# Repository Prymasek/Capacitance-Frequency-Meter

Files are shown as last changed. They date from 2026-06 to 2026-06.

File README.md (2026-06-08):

<div align="center">

# 🔬 ESP32-C3-Zero Capacitance & Frequency Meter

### Compact open-source capacitance and frequency meter

### Kompaktowy miernik pojemności i częstotliwości

<br>

🇵🇱 **Polski** | 🇬🇧 **English**

<br>

</div>

---

# 🇵🇱 Polski

## 📖 Opis projektu

**ESP32-C3-Zero Capacitance & Frequency Meter** to kompaktowy, otwartoźródłowy miernik pojemności oraz częstotliwości oparty na mikrokontrolerze **ESP32-C3-Zero**.

Projekt został stworzony jako niedrogie i praktyczne narzędzie pomiarowe do pracy z elektroniką. Urządzenie pozwala mierzyć pojemność kondensatorów od około **33 pF** oraz częstotliwość sygnałów cyfrowych do **250 kHz**.

Repozytorium zawiera zarówno część programową, jak i sprzętową projektu: firmware, schemat oraz projekt PCB wykonany w **KiCad 9.0**.

---

## 📸 Zdjęcia projektu

<div align="center">

### Gotowe urządzenie

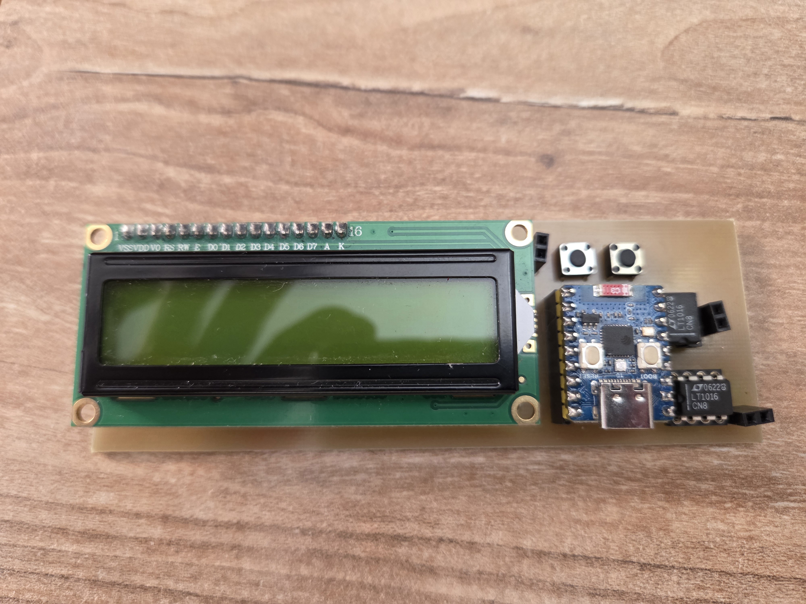
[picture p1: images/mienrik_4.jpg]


<br><br>

### Spód płytki PCB

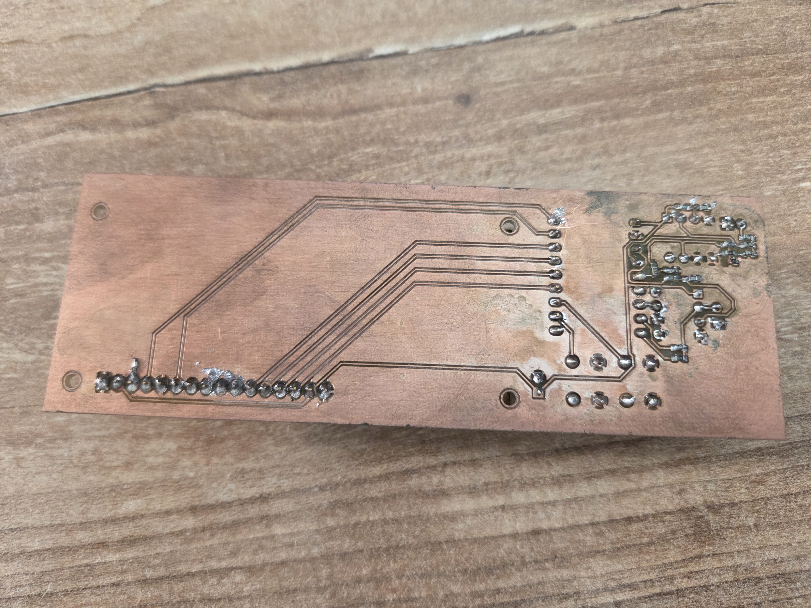
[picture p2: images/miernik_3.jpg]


<br><br>

### Wizualizacja 3D PCB

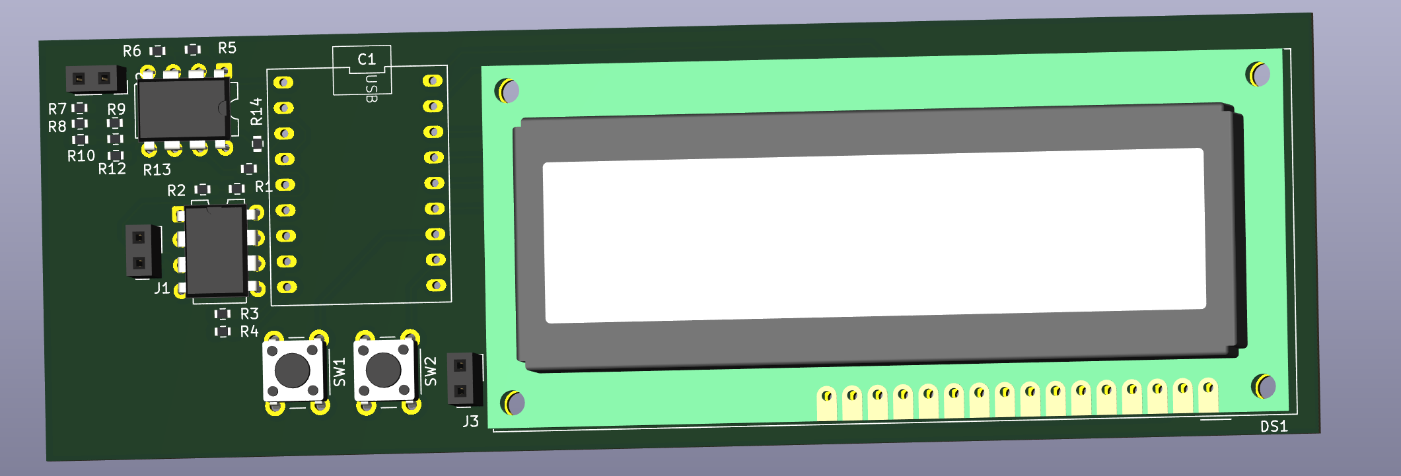
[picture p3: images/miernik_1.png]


</div>

---

## ✨ Najważniejsze funkcje

* ⚡ Pomiar pojemności kondensatorów
* 📡 Pomiar częstotliwości sygnałów
* 🔁 Automatyczny dobór zakresu pomiarowego
* 🎯 Funkcja TARE do kompensacji pojemności pasożytniczej
* ⏸️ Funkcja zatrzymania pomiaru częstotliwości
* 🧩 Projekt PCB wykonany w KiCad 9.0
* 🔓 Otwarty kod źródłowy
* 🛠️ Możliwość dalszej rozbudowy projektu

---

## ⚙️ Zasada działania

### ⚡ Pomiar pojemności

Pomiar pojemności realizowany jest poprzez pomiar czasu ładowania kondensatora przez rezystor o znanej wartości.

Mikrokontroler **ESP32-C3-Zero** mierzy czas potrzebny do osiągnięcia określonego progu napięcia wykrywanego przez szybki komparator **LT1016**.

W projekcie zastosowano dwa zakresy pomiarowe:

| Zakres | Rezystor |
| --- | --- |
| Małe pojemności | 100 kΩ |
| Duże pojemności | 2.2 kΩ |

Przełączanie zakresu odbywa się automatycznie w programie.

---

### 📡 Pomiar częstotliwości

Sygnał wejściowy podawany jest bezpośrednio na wejście mikrokontrolera ESP32-C3.

Każde narastające zbocze sygnału wywołuje przerwanie sprzętowe. Program zlicza impulsy w określonym czasie, a następnie przelicza wynik na częstotliwość.

Obsługiwane jednostki:

* Hz
* kHz
* MHz

---

## 🔧 Wykorzystane elementy

| Element | Opis |
| --- | --- |
| ESP32-C3-Zero | Główny mikrokontroler |
| LT1016 | Szybki komparator napięcia |
| Rezystor 100 kΩ | Zakres małych pojemności |
| Rezystor 2.2 kΩ | Zakres dużych pojemności |
| Przyciski TACT  | Sterowanie urządzeniem |
| Złącza goldpin  | Wejścia pomiarowe |

---

## 📦 Zawartość repozytorium

Repozytorium zawiera:

* 📄 Firmware dla ESP32-C3-Zero
* 🧩 Schemat elektryczny KiCad 9.0
* 🧩 Projekt PCB KiCad 9.0
* 📷 Zdjęcia gotowego urządzenia
* 📘 Dokumentację projektu

---

## 📂 Struktura projektu

```text
.
├── firmware/
│   └── cap&frq_meter.ino
│
├── hardware/
│   ├── cap&frq_meter.kicad_sch
│   └── cap&frq_meter.kicad_pcb
│
├── images/
│
├── README.md
└── LICENSE
```

---

## 🛠️ Oprogramowanie

Firmware został napisany w języku **C++** z wykorzystaniem środowiska **Arduino IDE** oraz rdzenia **Arduino Core for ESP32**.

Wykorzystane biblioteki:

* Arduino Core for ESP32
* LiquidCrystal

---

## 🚀 Możliwe rozszerzenia

* Pomiar ESR kondensatorów
* Pomiar rezystancji
* Pomiar indukcyjności
* Wyświetlacz OLED/TFT
* Zasilanie akumulatorowe
* Automatyczna kalibracja
* Rozszerzenie zakresów pomiarowych

---

<br>

<div align="center">

# 🇬🇧 English

</div>

---

## 📖 Project Description

**ESP32-C3-Zero Capacitance & Frequency Meter** is a compact open-source capacitance and frequency meter based on the **ESP32-C3-Zero** microcontroller.

The project was created as a low-cost and practical measurement tool for electronics work. The device can measure capacitor values starting from approximately **33 pF** and digital signal frequencies up to **250 kHz**.

This repository contains both the software and hardware parts of the project: firmware, schematic and PCB design created in **KiCad 9.0**.

---

## 📸 Project Gallery

<div align="center">

### Finished Device



<br><br>

### PCB Bottom Layer



<br><br>

### 3D PCB View



</div>

---

## ✨ Key Features

* ⚡ Capacitance measurement
* 📡 Frequency measurement
* 🔁 Automatic measurement range selection
* 🎯 TARE compensation for parasitic capacitance
* ⏸️ Frequency measurement hold function
* 🧩 PCB design created in KiCad 9.0
* 🔓 Open-source firmware
* 🛠️ Easy to modify and expand

---

## ⚙️ Operating Principle

### ⚡ Capacitance Measurement

Capacitance is measured by monitoring the charging time of a capacitor through a resistor with a known value.

The **ESP32-C3-Zero** measures the time required to reach a voltage threshold detected by the high-speed **LT1016** comparator.

Two measurement ranges are used:

| Range | Resistor |
| --- | --- |
| Small capacitances | 100 kΩ |
| Large capacitances | 2.2 kΩ |

Range switching is performed automatically in firmware.

---

### 📡 Frequency Measurement

The input signal is connected directly to an ESP32-C3 input pin.

Each rising edge of the signal generates a hardware interrupt. The firmware counts pulses over a defined time period and converts the result into frequency.

Supported units:

* Hz
* kHz
* MHz

---

## 🔧 Hardware Components

| Component | Description |
| --- | --- |
| ESP32-C3-Zero | Main microcontroller |
| LT1016 | High-speed voltage comparator |
| 100 kΩ resistor | Small capacitance range |
| 2.2 kΩ resistor | Large capacitance range |
| TACT switches | User controls |
| Pin headers | Measurement inputs |

---

## 📦 Repository Contents

This repository contains:

* 📄 Firmware for ESP32-C3-Zero
* 🧩 KiCad 9.0 schematic file
* 🧩 KiCad 9.0 PCB file
* 📷 Photos of the assembled device
* 📘 Project documentation

---

## 📂 Project Structure

```text
.
├── firmware/
│   └── cap&frq_meter.ino
│
├── hardware/
│   ├── cap&frq_meter.kicad_sch
│   └── cap&frq_meter.kicad_pcb
│
├── images/
│
├── README.md
└── LICENSE
```

---

## 🛠️ Software

The firmware is written in **C++** using **Arduino IDE** and **Arduino Core for ESP32**.

Libraries used:

* Arduino Core for ESP32
* LiquidCrystal

---

## 🚀 Future Improvements

* ESR measurement
* Resistance measurement
* Inductance measurement
* OLED/TFT display support
* Battery-powered version
* Automatic calibration
* Extended measurement ranges

---

## 📄 License

Released under the MIT License.

Feel free to use, modify and improve the project.

---

<div align="center">

### ⭐ If you like this project, consider leaving a star on GitHub.

</div>

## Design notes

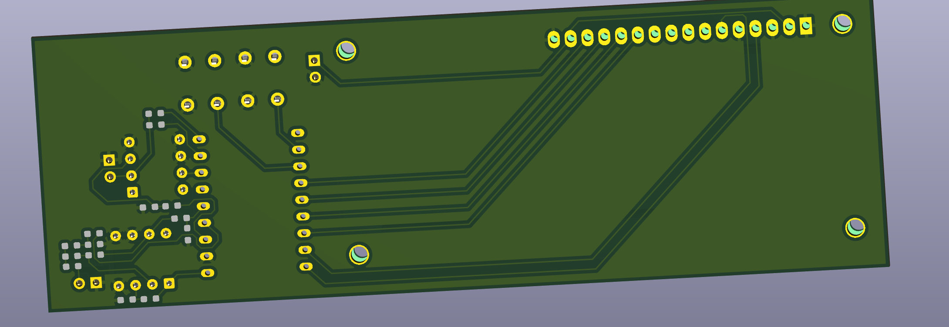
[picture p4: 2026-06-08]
images/miernik_2.png

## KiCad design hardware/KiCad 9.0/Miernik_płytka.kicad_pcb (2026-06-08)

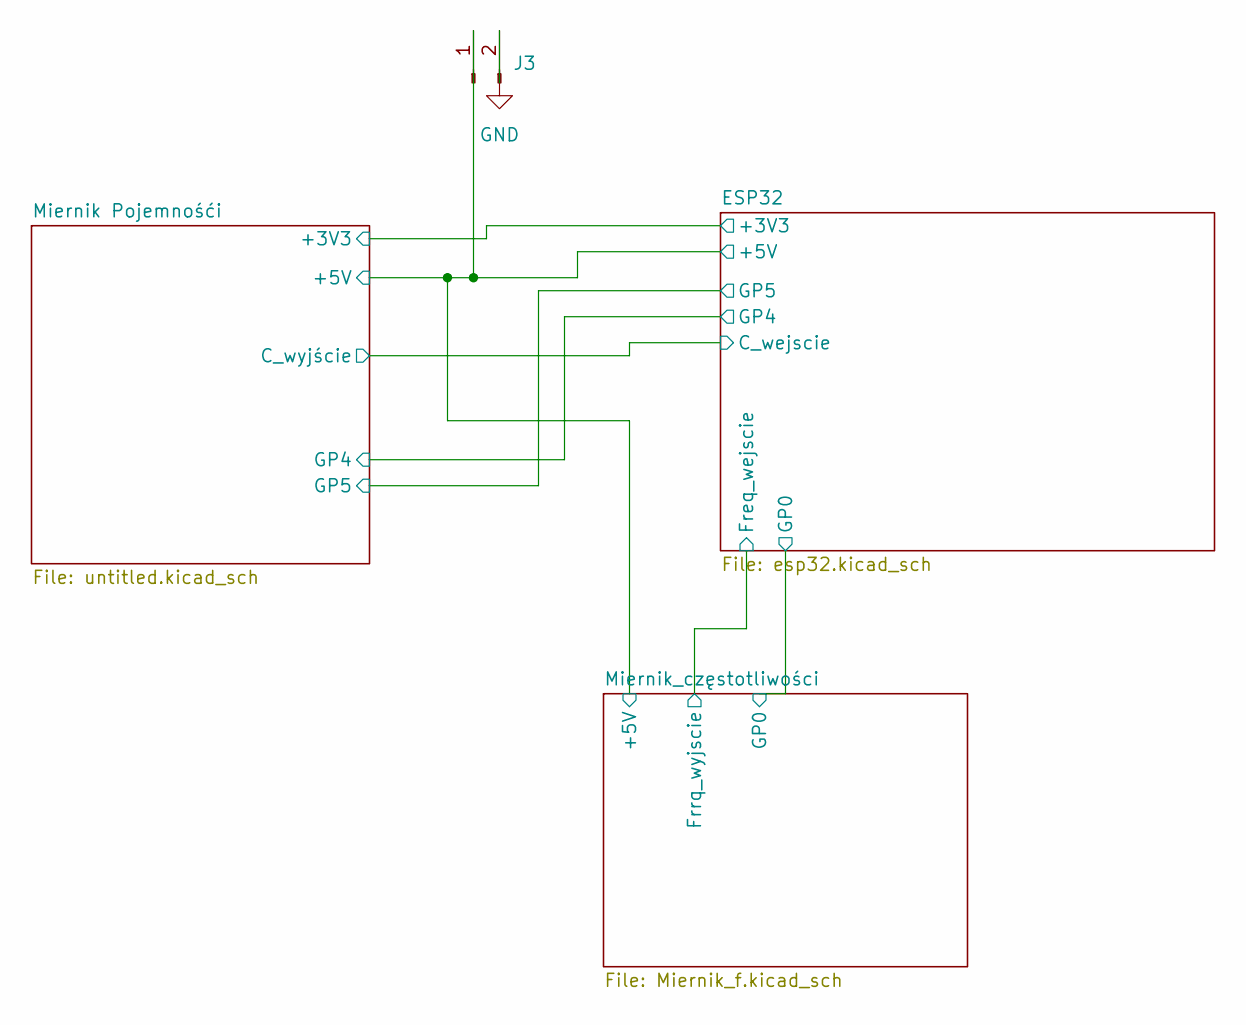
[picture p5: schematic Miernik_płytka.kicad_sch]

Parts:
J3: Conn_01x02_Pin; PinSocket_1x02_P2.54mm_Vertical

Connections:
/ESP32/+5V: J3.1; also elsewhere on the board
GND: J3.2; also elsewhere on the board

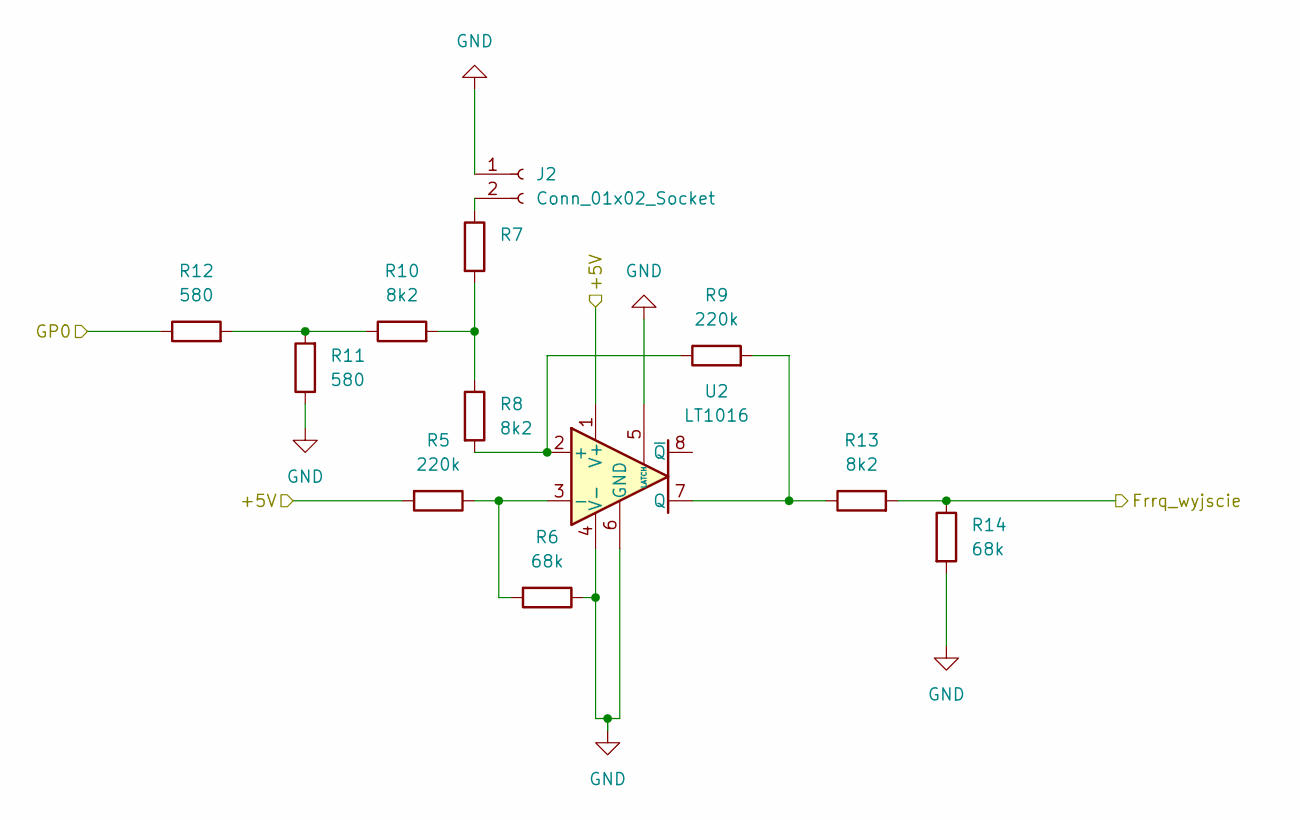
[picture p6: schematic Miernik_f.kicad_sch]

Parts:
J2: Conn_01x02_Socket; PinSocket_1x02_P2.54mm_Vertical
R5, R9: 220k; R_0603_1608Metric_Pad0.98x0.95mm_HandSolder
R6, R14: 68k; R_0603_1608Metric_Pad0.98x0.95mm_HandSolder
R7, R8, R10, R13: 8k2; R_0603_1608Metric_Pad0.98x0.95mm_HandSolder
R11, R12: 580; R_0603_1608Metric_Pad0.98x0.95mm_HandSolder
U2: LT1016; DIP-8_W7.62mm

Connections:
/ESP32/+5V: R5.2, U2.1 (V+); also elsewhere on the board
/ESP32/Freq_wejscie: R13.2, R14.1; also elsewhere on the board
/ESP32/GP0: R12.1; also elsewhere on the board
GND: J2.1, R6.1, R11.1, R14.2, U2.4 (V-), U2.5 (LATCH), U2.6 (GND); also elsewhere on the board
unnamed: J2.2, R7.1
unnamed: R10.1, R11.2, R12.2
unnamed: R7.2, R8.1, R10.2
unnamed: R8.2, R9.1, U2.2 (+)
unnamed: R5.1, R6.2, U2.3 (-)
unnamed: R9.2, R13.1, U2.7 (Q)

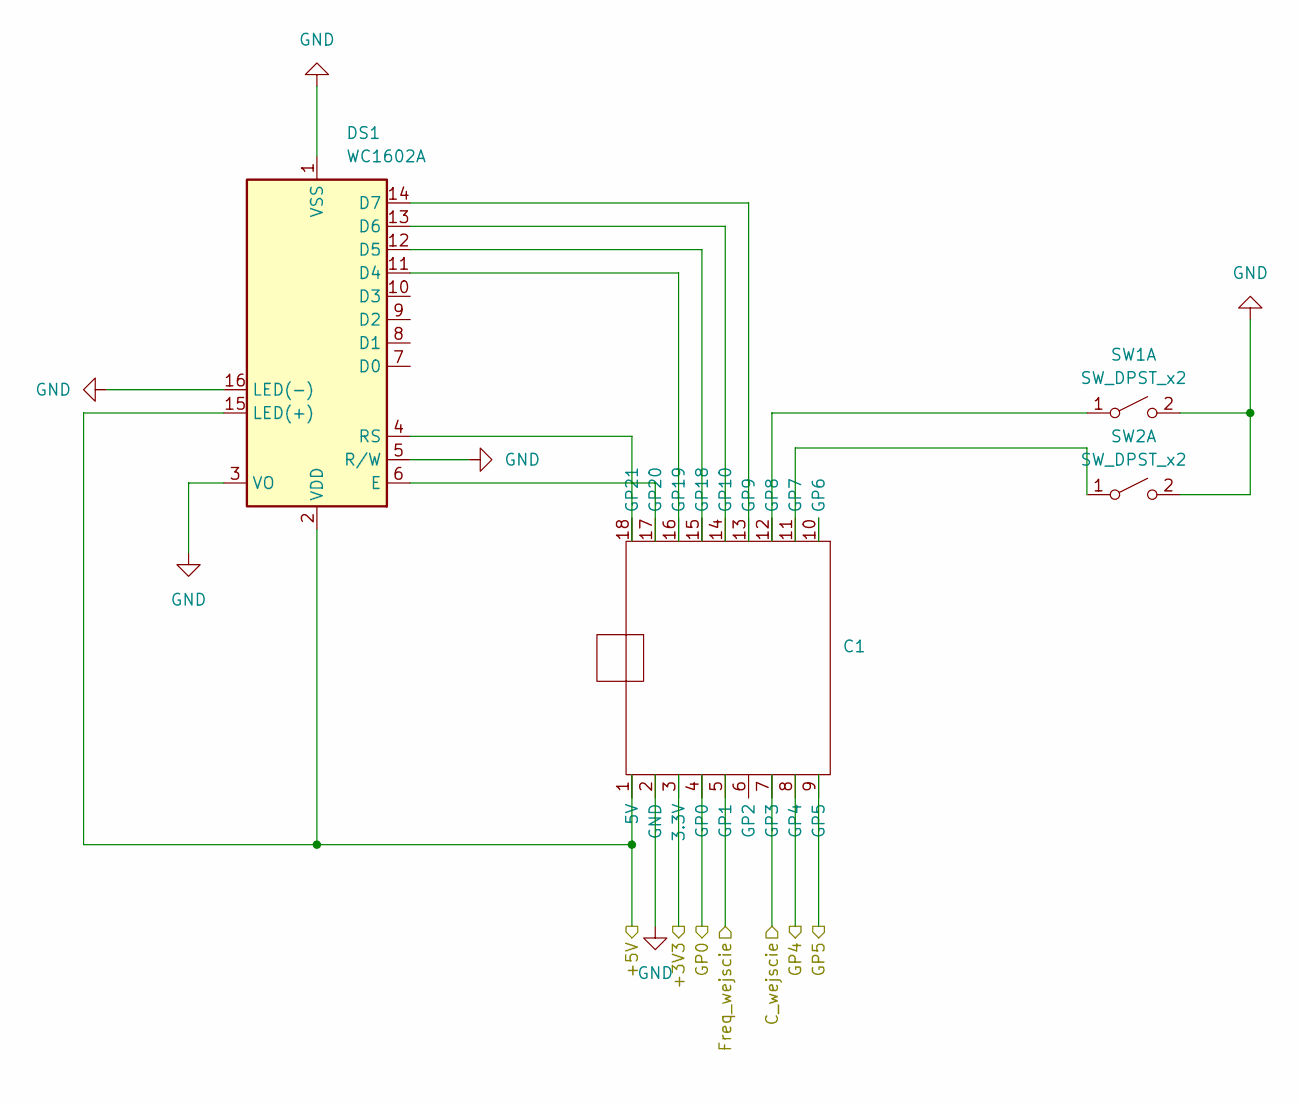
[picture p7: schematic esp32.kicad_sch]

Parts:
C1: ESP32_C3_ZERO
DS1: WC1602A
SW1, SW2: SW_DPST_x2; SW_PUSH_6mm_H4.3mm

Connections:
/ESP32/+3V3: C1.3 (3.3V); also elsewhere on the board
/ESP32/+5V: C1.1 (5V), DS1.2 (VDD), DS1.15 (LED(+)); also elsewhere on the board
/ESP32/C_wejscie: C1.7 (GP3); also elsewhere on the board
/ESP32/Freq_wejscie: C1.5 (GP1); also elsewhere on the board
/ESP32/GP0: C1.4 (GP0); also elsewhere on the board
/ESP32/GP4: C1.8 (GP4); also elsewhere on the board
/ESP32/GP5: C1.9 (GP5); also elsewhere on the board
GND: C1.2 (GND), DS1.1 (VSS), DS1.3 (VO), DS1.5 (R/W), DS1.16 (LED(-)), SW1.2 (B), SW2.2 (B); also elsewhere on the board
unnamed: C1.11 (GP7), SW2.1 (A)
unnamed: C1.12 (GP8), SW1.1 (A)
unnamed: C1.13 (GP9), DS1.14 (D7)
unnamed: C1.14 (GP10), DS1.13 (D6)
unnamed: C1.15 (GP18), DS1.12 (D5)
unnamed: C1.16 (GP19), DS1.11 (D4)
unnamed: C1.17 (GP20), DS1.6 (E)
unnamed: C1.18 (GP21), DS1.4 (RS)

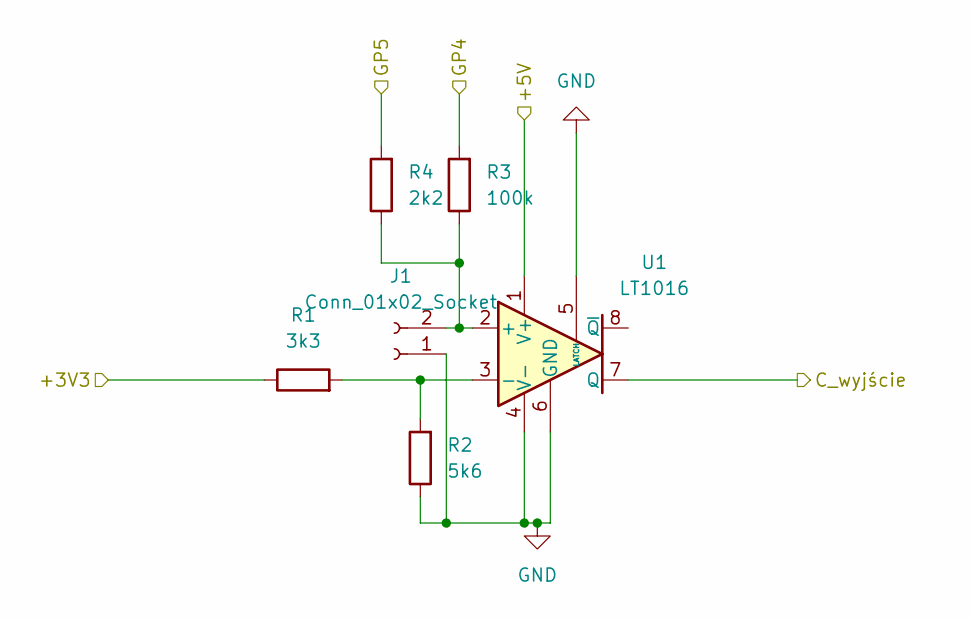
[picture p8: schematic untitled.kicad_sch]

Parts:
J1: Conn_01x02_Socket; PinSocket_1x02_P2.54mm_Vertical
R1: 3k3; R_0603_1608Metric_Pad0.98x0.95mm_HandSolder
R2: 5k6; R_0603_1608Metric_Pad0.98x0.95mm_HandSolder
R3: 100k; R_0603_1608Metric_Pad0.98x0.95mm_HandSolder
R4: 2k2; R_0603_1608Metric_Pad0.98x0.95mm_HandSolder
U1: LT1016; DIP-8_W7.62mm

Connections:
/ESP32/+3V3: R1.1; also elsewhere on the board
/ESP32/+5V: U1.1 (V+); also elsewhere on the board
/ESP32/C_wejscie: U1.7 (Q); also elsewhere on the board
/ESP32/GP4: R3.2; also elsewhere on the board
/ESP32/GP5: R4.2; also elsewhere on the board
GND: J1.1, R2.1, U1.4 (V-), U1.5 (LATCH), U1.6 (GND); also elsewhere on the board
unnamed: J1.2, R3.1, R4.1, U1.2 (+)
unnamed: R1.2, R2.2, U1.3 (-)

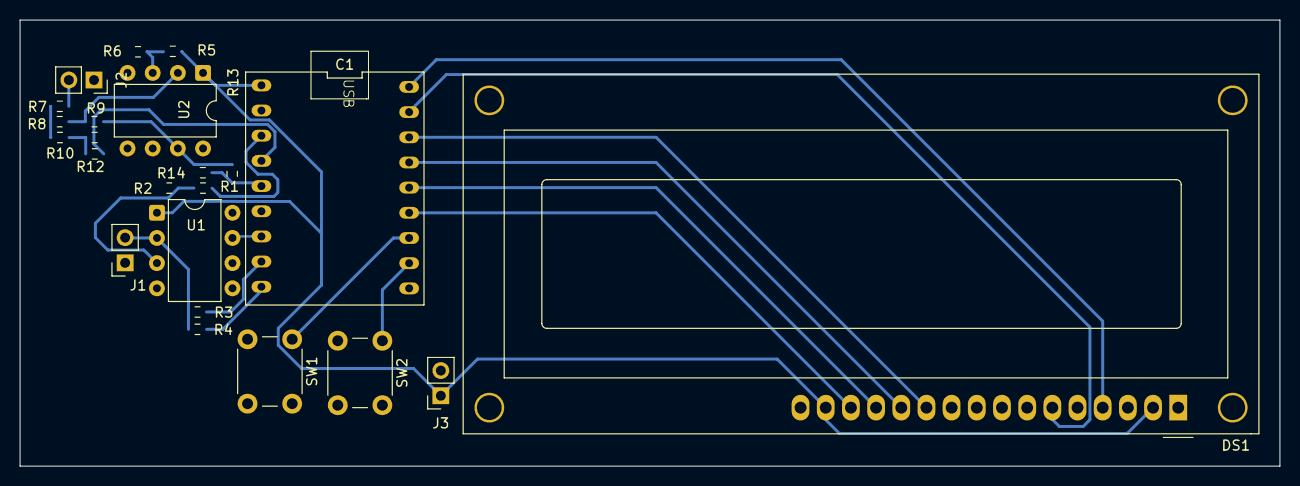
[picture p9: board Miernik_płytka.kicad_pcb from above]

Board: 2 copper layers, 127.1 x 45.0 mm, 23 parts (0 on the bottom side), 24 nets.

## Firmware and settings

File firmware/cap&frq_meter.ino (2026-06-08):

#include <Arduino.h>
#include <LiquidCrystal.h>

// --- Konfiguracja PINów ---
const int rs = 21, en = 20, d4 = 19, d5 = 18, d6 = 10, d7 = 9;
const int chargePin = 4;
const int compPinC = 3;
const int freqInputPin = 6;
const int btnModePin = 8;
const int btnTarePin = 7;

LiquidCrystal lcd(rs, en, d4, d5, d6, d7);

// --- Zmienne globalne ---
enum Mode { MODE_CAPACITANCE, MODE_FREQUENCY };
Mode currentMode = MODE_CAPACITANCE;

bool isPaused = false;
float offset_nF = 0.0;
const float R = 100000.0; // 100k Ohm
unsigned long lastCapMeasureTime = 0; // Czas ostatniego pomiaru C

// Zmienne dla pojemności (C)
volatile uint32_t t_start = 0;
volatile uint32_t t_stop = 0;
volatile bool doneC = false;

// Zmienne dla częstotliwości (F)
volatile unsigned long pulseCount = 0;
bool lastFreqState = false;
unsigned long lastPulseTime = 0;
unsigned long currentPeriod = 0;
unsigned long lastReportTime = 0;

// --- Przerwania ---
void IRAM_ATTR onComparatorMatch() {
  t_stop = micros();
  digitalWrite(chargePin, LOW);
  doneC = true;
}

void setup() {
  lcd.begin(16, 2);
  lcd.print("Miernik C i f");
  lcd.setCursor(0, 1);
  lcd.print("V2.0 - Rozszerz.");
  delay(2000);

  pinMode(chargePin, OUTPUT);
  digitalWrite(chargePin, LOW);
  pinMode(compPinC, INPUT);
  pinMode(freqInputPin, INPUT);
  pinMode(btnModePin, INPUT_PULLUP);
  pinMode(btnTarePin, INPUT_PULLUP);

  attachInterrupt(digitalPinToInterrupt(compPinC), onComparatorMatch, RISING);
  lcd.clear();
}

void showTransition(const char* text) {
  lcd.clear();
  lcd.setCursor(0, 0);
  lcd.print("TRYB:");
  lcd.setCursor(0, 1);
  lcd.print(text);
  delay(1500);
  lcd.clear();
}

// --- Funkcja formatująca jednostki C ---
void displayCapacitance(float nF) {
  lcd.setCursor(0, 0);
  lcd.print("C: ");
  if (nF < 1.0) {
    lcd.print(nF * 1000.0, 1);
    lcd.print(" pF     ");
  } else if (nF >= 1000.0) {
    lcd.print(nF / 1000.0, 3);
    lcd.print(" uF     ");
  } else {
    lcd.print(nF, 3);
    lcd.print(" nF     ");
  }
}

void handleCapacitance() {
  unsigned long currentMillis = millis();

  // Obsługa tary (wymusza natychmiastowy pomiar)
  if (digitalRead(btnTarePin) == LOW) {
    doneC = false;
    t_start = micros();
    digitalWrite(chargePin, HIGH);
    uint32_t t0 = millis();
    while (!doneC && (millis() - t0 < 1000)) yield();
    if (doneC) {
      offset_nF = ((float)(t_stop - t_start) / R) * 1000.0;
      lcd.setCursor(0, 1);
      lcd.print("TARA: OK!      ");
      delay(800);
    }
    lastCapMeasureTime = currentMillis; // Resetuj timer po tarowaniu
  }

  // Pomiar co 10 sekund (lub jeśli to pierwszy pomiar)
  if (currentMillis - lastCapMeasureTime >= 10000 || lastCapMeasureTime == 0) {
    doneC = false;
    t_start = micros();
    digitalWrite(chargePin, HIGH);

    uint32_t startTimeCheck = millis();
    while (!doneC && (millis() - startTimeCheck < 3000)) {
      if (digitalRead(btnModePin) == LOW) return; 
      yield();
    }

    if (doneC) {
      float deltaT = (float)(t_stop - t_start);
      float raw_nF = (deltaT / R) * 1000.0;
      float capacitance_nF = raw_nF - offset_nF;
      if (capacitance_nF < 0) capacitance_nF = 0;

      displayCapacitance(capacitance_nF);
      lcd.setCursor(0, 1);
      lcd.print("T: "); lcd.print((int)deltaT); lcd.print(" us    ");
    } else {
      digitalWrite(chargePin, LOW);
      lcd.setCursor(0, 0);
      lcd.print("Brak kondensat.");
      lcd.setCursor(0, 1);
      lcd.print("Timeout / Open ");
    }
    lastCapMeasureTime = currentMillis;
  } else {
    // Odliczanie do następnego pomiaru na LCD (opcjonalne)
    lcd.setCursor(13, 0);
    lcd.print((10000 - (currentMillis - lastCapMeasureTime)) / 1000);
    lcd.print("s ");
  }
}

void handleFrequency() {
  unsigned long now = millis();
  unsigned long nowMicros = micros();

  static bool lastTareBtnState = HIGH;
  bool currentTareBtnState = digitalRead(btnTarePin);
  if (currentTareBtnState == LOW && lastTareBtnState == HIGH) {
    isPaused = !isPaused;
    delay(50);
  }
  lastTareBtnState = currentTareBtnState;

  if (isPaused) {
    lcd.setCursor(13, 0);
    lcd.print("[H]");
    return; 
  }

  bool currentState = digitalRead(freqInputPin);
  if (currentState == HIGH && lastFreqState == LOW) {
    pulseCount++;
    currentPeriod = nowMicros - lastPulseTime;
    lastPulseTime = nowMicros;
  }
  lastFreqState = currentState;

  if (now - lastReportTime >= 1000) {
    float frequency = (float)pulseCount;
    
    lcd.clear();
    lcd.setCursor(0, 0);
    lcd.print("f: "); 
    if (frequency >= 1000.0) {
      lcd.print(frequency / 1000.0, 3); lcd.print(" kHz");
    } else {
      lcd.print(frequency, 1); lcd.print(" Hz");
    }

    lcd.setCursor(0, 1);
    if (pulseCount > 0) {
      float periodMs = currentPeriod / 1000.0;
      if (periodMs < 1.0) {
        lcd.print("T: "); lcd.print(periodMs * 1000.0, 1); lcd.print(" us");
      } else {
        lcd.print("T: "); lcd.print(periodMs, 2); lcd.print(" ms");
      }
    } else {
      lcd.print("Brak sygnalu");
    }

    pulseCount = 0;
    lastReportTime = now;
  }
}

void loop() {
  if (digitalRead(btnModePin) == LOW) {
    delay(50); 
    if (currentMode == MODE_CAPACITANCE) {
      currentMode = MODE_FREQUENCY;
      showTransition("CZESTOTLIWOSC");
    } else {
      currentMode = MODE_CAPACITANCE;
      showTransition("POJEMNOSC");
      lastCapMeasureTime = 0; // Wymuś natychmiastowy pomiar po powrocie
    }
    while(digitalRead(btnModePin) == LOW); 
  }

  if (currentMode == MODE_CAPACITANCE) {
    handleCapacitance();
  } else {
    handleFrequency();
  }
}
